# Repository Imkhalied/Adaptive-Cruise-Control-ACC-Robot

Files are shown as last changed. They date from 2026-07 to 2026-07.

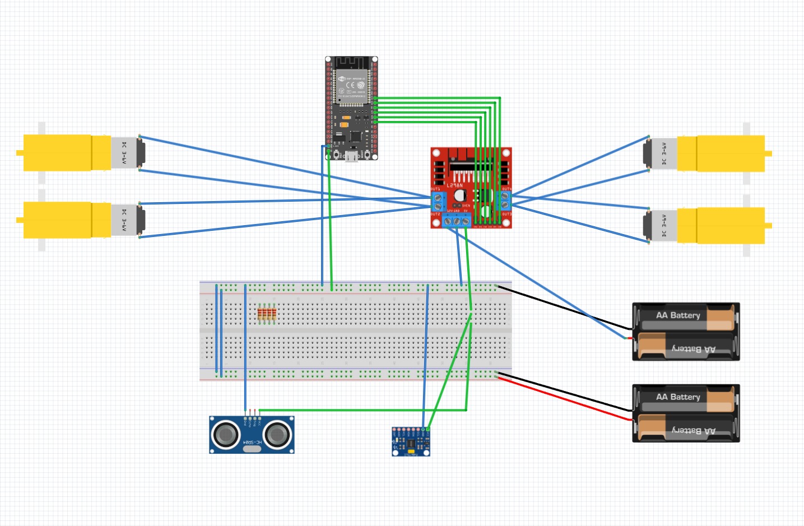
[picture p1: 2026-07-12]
Images/Wiring.jpeg

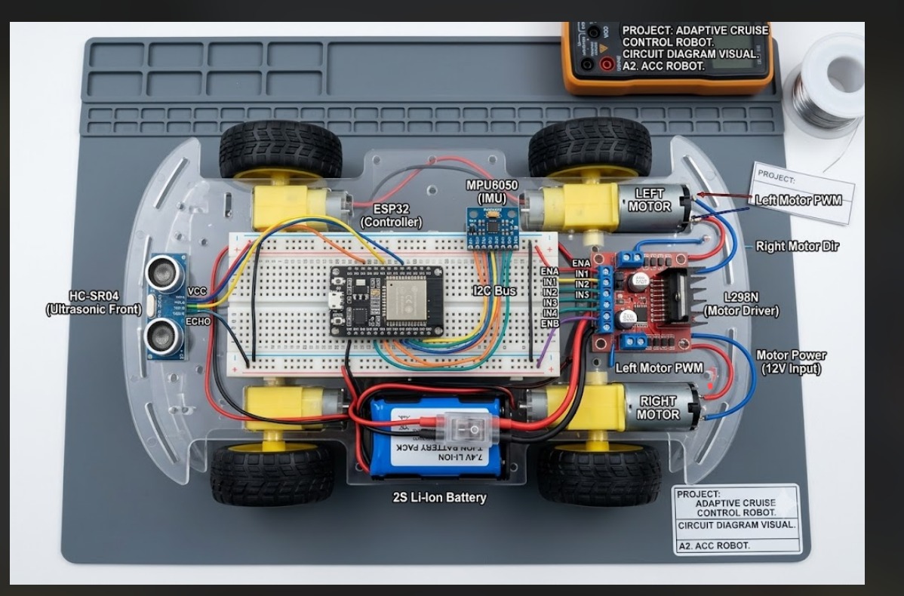
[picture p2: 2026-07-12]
Images/Robot top view.jpeg

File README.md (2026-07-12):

# Adaptive Cruise Control (ACC) Robot using TinyML & PID Control

## Project Overview

Development of an intelligent Adaptive Cruise Control (ACC) robot that combines PID control and TinyML to maintain a safe following distance. The project integrates real-time sensor data, embedded AI, and autonomous speed control on an ESP32 platform.

Completed as the capstone project of the **Robotics & Artificial Intelligence Scholarship Program (90 Hours)** at EncryptCore.

---

## Project Contents

- Adaptive Cruise Control (ACC) robot development
- ESP32 embedded control system
- HC-SR04 ultrasonic distance sensing
- MPU6050 IMU integration
- MATLAB PID controller design and tuning
- Edge Impulse TinyML model training
- Real-world dataset collection and labeling
- AI deployment on ESP32 using the Edge Impulse C++ library
- Hardware design and wiring using Fritzing

---

## Tools Used

- Arduino IDE
- ESP32
- MATLAB
- Edge Impulse
- Fritzing
- C++

---

## Performance

- Robotics & AI Scholarship: **90 Hours**
- TinyML Classification Accuracy: **100%**
- Driving States:
  - Too Close
  - Safe Distance
  - Too Far

---

## Supervision

- Mohamed Mahmoud

---

## Author

Khaled Diaa – Mechatronics Engineering Student

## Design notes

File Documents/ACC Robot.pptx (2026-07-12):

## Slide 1

ADAPTIVE CRUISE CONTROL ROBOT

A Build Guide for a Sensor-Driven, PID-Controlled Follower Robot

ESP32 · HC-SR04 · MPU6050 · L298N · PID Control

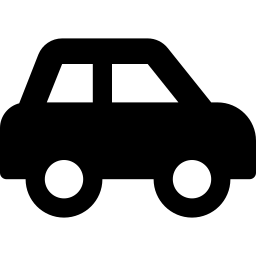
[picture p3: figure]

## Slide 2

Project Overview

What is Adaptive Cruise Control?

Standard cruise control holds a constant speed. ACC intelligently adjusts speed to maintain a safe, pre-defined distance from the vehicle ahead.

System Architecture

Inputs

Distance from HC-SR04, tilt/acceleration from MPU6050

Processing

ESP32 running a PID controller or an AI inference model

Outputs

PWM signals to the L298N driver, commanding the DC motors

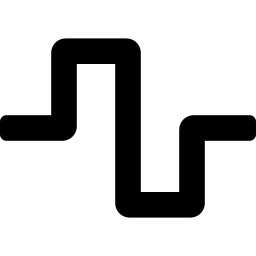
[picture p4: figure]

How Real Vehicles Do It

Radar or LiDAR on the front grille bounces waves off the lead car. Time-of-flight gives distance; if the lead car slows, the ECU commands the brakes and throttle to decelerate.

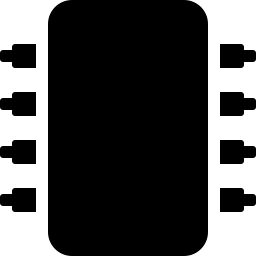
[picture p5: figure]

How Our Robot Mimics It

An HC-SR04 plays radar, the ESP32 plays ECU, and instead of brakes it adjusts PWM to the L298N driver — speeding up or slowing the DC motors via a PID loop or an AI model.

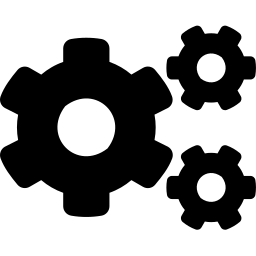
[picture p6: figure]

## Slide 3

Core Components — Sensing & Control

ESP32

3.3V logic · ~500mA peak

The robot's brain. A dual-core 32-bit MCU that runs the control code, reads sensors, and generates PWM. Strictly 3.3V — 5V on a pin can destroy it.

HC-SR04 Ultrasonic

5V · ~15mA

Acts as the radar. Emits a 40kHz pulse from Trig and reads the echo on Echo; distance is derived from time of flight. Struggles with soft or angled surfaces.

MPU6050

3.3–5V · I2C (SDA/SCL)

Accelerometer + gyroscope that detects tilt, bumps, and slopes using MEMS capacitance sensing, feeding the control loop extra context.

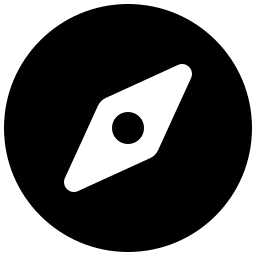
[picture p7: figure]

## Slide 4

Core Components — Drive & Power

L298N Motor Driver

Up to 35V, 2A/channel

A heavy-duty H-Bridge switch that supplies motor current the ESP32 can't provide directly, and lets current reverse for forward/reverse driving. Drops ~2V from battery to motors.

DC Motors + Gearbox

Lorentz force

Convert electrical energy into torque: current through a coil in a magnetic field creates rotational force that turns the wheels.

Battery Pack

2x 18650 Li-Ion, 7.4V

Powers the whole system. Two 18650 cells in series are recommended over a 9V battery, which lacks the capacity this build needs.

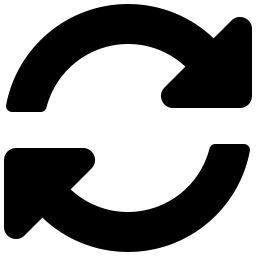
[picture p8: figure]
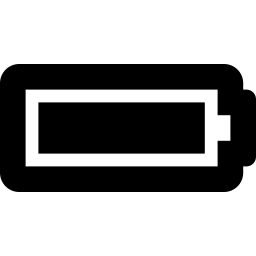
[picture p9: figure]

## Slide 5

Power System

Two 18650 Li-Ion cells in series (3.7V × 2)

7.4V

Nominal voltage

8.4V

Fully charged

2500mAh

Capacity

~3.5 hrs

Estimated runtime

Current Draw

Motors: 2 × ~250mA running (stall up to 1.5A)
ESP32 + sensors: ~200mA
Total average: ~700mA

Protection

Always use a battery holder with a built-in protection circuit (BMS) to prevent discharging the 18650s below 3.0V per cell, which permanently ruins them.

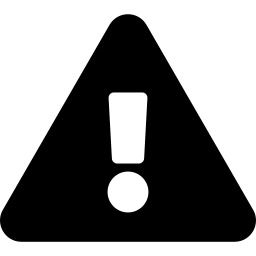
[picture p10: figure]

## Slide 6

Robot Workflow

The robot runs an infinite loop — constantly sensing, thinking, and acting.

1

START

Power on

2

INIT

Set up ESP32 pins, I2C bus; init MPU6050 & HC-SR04

3

SENSE

Trigger HC-SR04, read Echo, calc distance; read MPU6050 tilt

4

FILTER

Apply a moving-average filter to smooth distance spikes

5

DECIDE

Compare filtered distance to target via PID / AI

6

ACT

Send PWM signals to the L298N to drive the motors

→

→

→

→

→

7. REPEAT — loop back to SENSE, continuously

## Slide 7

Distance Control & Filtering

< 10 cm

Emergency Stop

Object too close — speed = 0 immediately

30 cm

Safe Distance

Target distance — robot matches lead speed

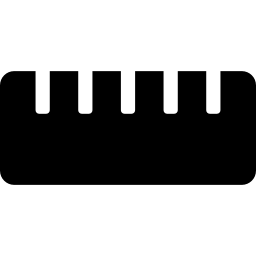
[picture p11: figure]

> 100 cm

Max Following

Object far — robot cruises at top speed

Distance Calculation (Time of Flight)

Distance = (Speed of Sound × Time) / 2

Speed of sound at sea level ≈ 343 m/s (0.0343 cm/µs)

The sound wave travels to the object and back, so the raw time-of-flight is halved.

Moving Average Filter

Filtered = (x₁ + x₂ + ... + xₙ) / n

Ultrasonic readings occasionally spike to "0" or "400cm" from missed echoes.

Keeping the last 5 readings and averaging them smooths out these erratic jumps.

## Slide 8

PID Control

The industry-standard closed-loop control method — calculates an error and outputs a motor speed.

u(t) = Kp·e(t) + Ki∫e(τ)dτ + Kd·de(t)/dt

Proportional (Kp)

Reacts to the present error. Far from 30cm → drive fast; close → drive slow. Can cause overshoot on its own.

Tuning by trial and error:

P

Integral (Ki)

Looks at past error, summing steady-state error over time to nudge the robot if it stalls just short of target.

I

Derivative (Kd)

Predicts future error from the rate of change of distance, acting as a brake to prevent overshoot.

D

- Set Ki and Kd to 0; raise Kp until the robot oscillates around the safe distance.
- Raise Kd to dampen the oscillation so it settles smoothly.
- Raise Ki slightly if the robot stops just short of the target.

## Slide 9

AI / Machine Learning Integration

Instead of classical PID, ML can map sensor inputs directly to motor outputs.

Option 1: Edge Impulse Classification

Data collection: record ultrasonic + MPU accelerometer arrays
Classes: "Too Close", "Safe Distance", "Too Far"
Deployment: exported as an Arduino library; ESP32 runs inference and sets motor speed from the winning class

Recommendation

Option 2: Regression Model

Instead of discrete buckets, regression predicts a continuous PWM speed (0–255) from features like current distance and rate of change of distance.

Gives smoother speed transitions than classification, which tends to produce jerky, stepped changes.

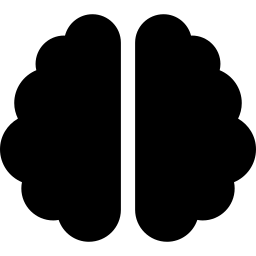
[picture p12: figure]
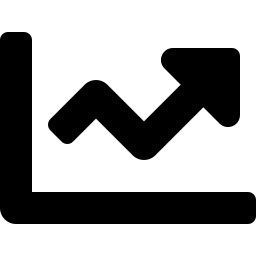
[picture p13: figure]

For a beginner, PID is the standard and most educational approach. If you do use AI, prefer Regression — Classification tends to cause jerky, stepped speed changes.

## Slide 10

Calibration & Testing

Sensor Calibration

HC-SR04:
Measure an object exactly 20cm away with a ruler. Adjust the 0.034 multiplier in code until the Serial Monitor reads exactly 20cm.
MPU6050:
Place the robot on a flat surface. Raw X, Y, Z should read 0, 0, 1g — the deviations are your offsets to subtract in software.

Golden Rule

Never combine sensors and motors on the first power-up. Validate each subsystem in isolation, then integrate one piece at a time.

Order of operations

- Calibrate HC-SR04 distance reading
- Zero the MPU6050 offsets
- Bench-test sensors alone
- Bench-test motors alone (wheels raised)
- Full integration test on the floor

Testing Checklist

- Bench-test sensors: no motors connected — wave a hand in front of the sensor and confirm distance changes on the Serial Monitor

- Bench-test motors: wheels off the ground, force analogWrite(enA, 255) — both should spin forward; swap L298N wiring if one runs backward

- Integration test: on the floor, walk in front of it — does it follow, and stop when you stop?

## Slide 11

Troubleshooting

Problem | Likely Cause | Solution
ESP32 randomly resets/reboots | Voltage drop from motors starting up | Power ESP32 from a separate buck converter, or add a large capacitor across the power rails
Robot stutters / shakes | PID Kp is too high (overshoot) | Decrease Kp; increase Kd slightly
Motors hum but don't spin | PWM speed is below the motor's deadband | Add a minimum baseline speed in code (e.g. if speed > 0, speed += 50)
Distance reads 0cm randomly | Ultrasonic echo timed out | Implement a software filter to ignore 0 readings

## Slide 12

Future Improvements

Once the base robot works, consider these engineering upgrades:

Wheel Encoders

The control loop is currently "open-loop" for the motors — we guess that a PWM of 150 equals a certain speed. Wheel encoders measure actual wheel RPM, enabling a cascaded PID loop: the distance PID outputs a target RPM, and a speed PID achieves it.

Sensor Fusion

Combine HC-SR04 distance with MPU6050 accelerometer data using a Kalman Filter to predict where the lead vehicle is, even when the ultrasonic sensor temporarily misses a ping.

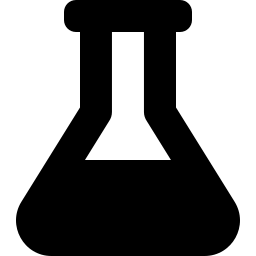
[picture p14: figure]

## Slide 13

Final Deliverables

Through this guide, you now have:

A complete architectural overview of an ACC system

A detailed pin mapping and wiring strategy for voltage compatibility

A structural workflow and flowchart logic

The mathematical foundation of PID control

A starter codebase demonstrating proportional control

Testing, calibration, and troubleshooting protocols

Take your time with the wiring, build the circuit incrementally, and test each component alone before combining them into the final control loop. Good luck with your build!

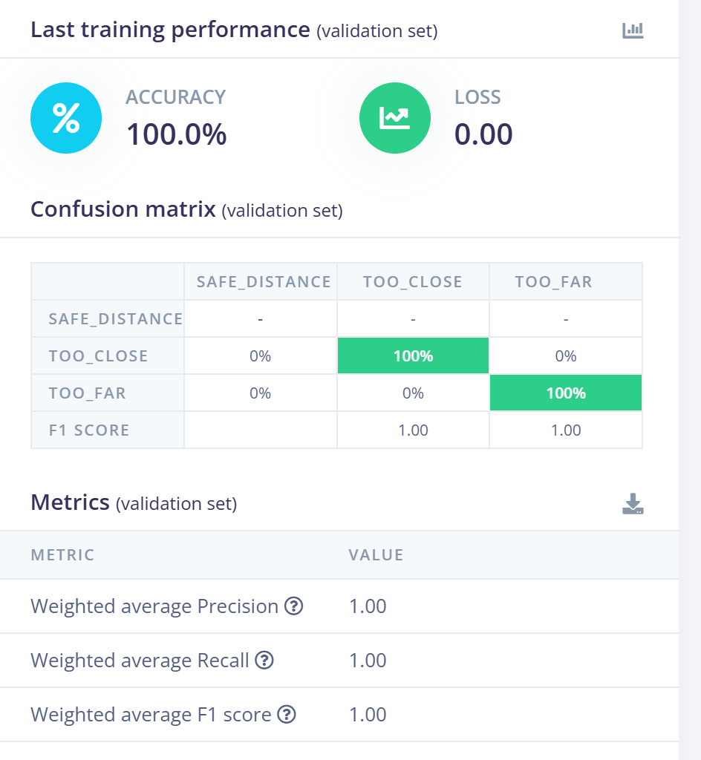
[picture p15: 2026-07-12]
Images/Model Accuracy.png

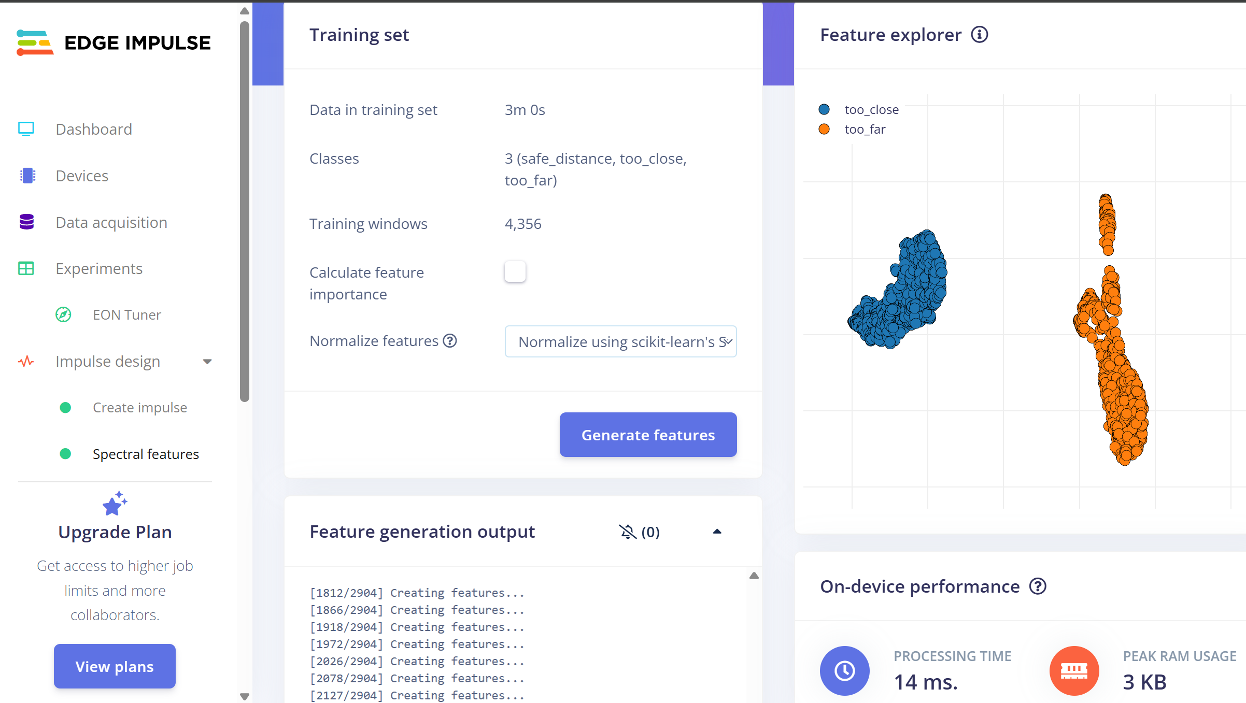
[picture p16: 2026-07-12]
Images/Model Traning.png

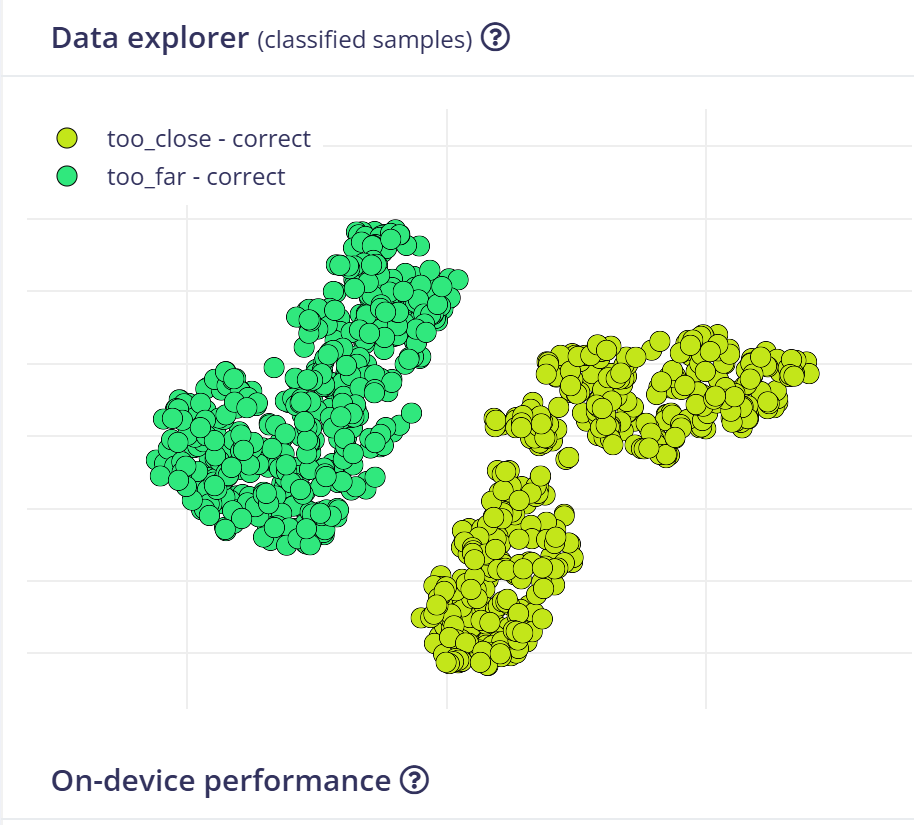
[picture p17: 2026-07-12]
Images/model Classified.png

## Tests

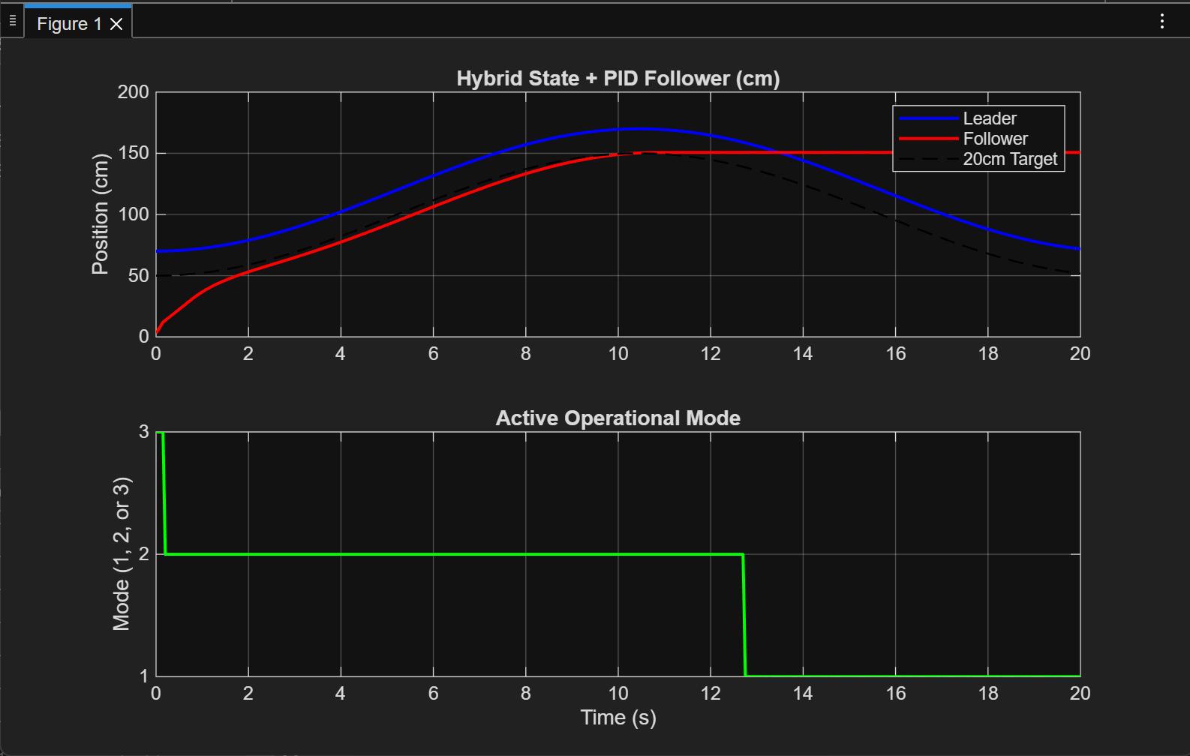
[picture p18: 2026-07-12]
Images/Matlab results.png

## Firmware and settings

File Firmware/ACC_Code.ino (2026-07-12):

// =====================================================
// ROBOT 2 — FOLLOWER (PID + HC-SR04 + Edge Impulse AI)
// Maintains fixed distance behind Leader.
// Emergency brake if gap < 8cm.
// PID setpoint tracks Leader's actual gap in real time.
// Edge Impulse fusion classifier ("safe_distance" /
// "too_close" / "too_far") runs alongside the PID loop
// and can override/bias motor output as a safety layer.
//
// FIXED FOR ESP32 ARDUINO CORE 3.x:
// ledcSetup() / ledcAttachPin() were removed in core 3.x.
// New API attaches LEDC directly to a pin with ledcAttach(),
// and writes duty cycle with ledcWrite(pin, duty) — no more
// separate channel numbers to manage.
//
// ── EDGE IMPULSE SETUP (read this first) ────────────
// 1. Install the library: Arduino IDE > Sketch > Include
//    Library > Add .ZIP Library... > select the ORIGINAL
//    zip (ei-ai-project-arduino-1_0_2-impulse-_1.zip),
//    not the extracted folder. That registers it correctly
//    under the name "AI_project_inferencing".
// 2. This is a SENSOR FUSION model: 8 axes/frame, 50
//    frames/window, sampled at 50 Hz (20 ms/sample) -> a
//    1-second window per inference. Its DSP block uses an
//    FFT + low-pass filter (9.7 Hz cutoff), so the 50 Hz
//    sample rate must be hit consistently or accuracy will
//    degrade — this is why the loop below is restructured
//    to be non-blocking (millis()-based) instead of using
//    delay().
// 3. IMPORTANT — VERIFY THE FEATURE ORDER: the exported
//    library does NOT embed axis names for fusion projects,
//    so the exact order of the 8 values below is an
//    assumption, not a certainty. I picked the most likely
//    layout given your hardware (HC-SR04 + MPU6050) and the
//    labels (safe_distance/too_close/too_far):
//
//      [0] distance_filtered (cm)
//      [1] distance_raw      (cm)
//      [2] accX (m/s^2)
//      [3] accY (m/s^2)
//      [4] accZ (m/s^2)
//      [5] gyroX (deg/s)
//      [6] gyroY (deg/s)
//      [7] gyroZ (deg/s)
//
//    Open your Edge Impulse project > Data acquisition, and
//    check the sensor/axis order shown for your recorded
//    samples. If it differs, reorder ONLY the 8 lines inside
//    sampleFeatures() below — nothing else needs to change.
// =====================================================

#include <Wire.h>
#include <MPU6050.h>
#include <AI_project_inferencing.h>   // Edge Impulse: AI_project

// ── HC-SR04 ──────────────────────────────────────────
#define TRIG  5
#define ECHO 18

// ── Motor Pins ──────────────────────────────────────
#define ENA  25
#define IN1  26
#define IN2  27
#define ENB  14
#define IN3  12
#define IN4  13

#define PWM_FREQ 1000
#define PWM_RES  8

// ── PID Parameters (TUNE THESE) ─────────────────────
float Kp = 3.0;
float Ki = 0.05;
float Kd = 1.5;

const float TARGET_DIST   = 20.0;  // cm — desired following gap
const float ESTOP_DIST    =  8.0;  // cm — emergency brake threshold
const float TOO_FAR_DIST  = 60.0;  // cm — max range before full speed
const float MAX_PWM       = 220.0;
const float MIN_PWM       =  60.0;

// ── PID state ───────────────────────────────────────
float prevError  = 0;
float integral   = 0;
unsigned long prevTime = 0;

// ── MPU6050 ─────────────────────────────────────────
MPU6050 mpu;
int16_t rawAx, rawAy, rawAz, rawGx, rawGy, rawGz;

// ── Sensor noise filter ─────────────────────────────
float distFiltered = TARGET_DIST;
const float ALPHA = 0.3;   // Low-pass: 0=frozen, 1=raw

// ── Control loop timing (non-blocking) ──────────────
const unsigned long CONTROL_INTERVAL_MS = 40;  // ~25 Hz, same as before
unsigned long lastControlMs = 0;

// =====================================================
// EDGE IMPULSE — feature buffer & classifier plumbing
// =====================================================
#define EI_SAMPLE_INTERVAL_MS (1000 / EI_CLASSIFIER_FREQUENCY)  // 20 ms @ 50 Hz
static float eiFeatures[EI_CLASSIFIER_RAW_SAMPLE_COUNT * EI_CLASSIFIER_RAW_SAMPLES_PER_FRAME]; // 50*8 = 400
static size_t eiFeatureIx = 0;
unsigned long lastEiSampleMs = 0;

// Latest classifier verdict, used by the control loop
enum FollowState { STATE_SAFE, STATE_TOO_CLOSE, STATE_TOO_FAR, STATE_UNKNOWN };
FollowState eiState = STATE_UNKNOWN;
float eiConfidence = 0.0f;

// Required by the Edge Impulse SDK: feeds raw features to the classifier
int raw_feature_get_data(size_t offset, size_t length, float *out_ptr) {
  memcpy(out_ptr, eiFeatures + offset, length * sizeof(float));
  return 0;
}

// Grabs one frame (8 values) of sensor data for the EI feature buffer.
// See the "VERIFY THE FEATURE ORDER" note at the top of this file.
void sampleFeatures() {
  float rawDist = readDistance();
  distFiltered = ALPHA * rawDist + (1.0f - ALPHA) * distFiltered;

  mpu.getMotion6(&rawAx, &rawAy, &rawAz, &rawGx, &rawGy, &rawGz);
  float accX = (rawAx / 16384.0f) * 9.80665f;
  float accY = (rawAy / 16384.0f) * 9.80665f;
  float accZ = (rawAz / 16384.0f) * 9.80665f;
  float gyroX = rawGx / 131.0f;
  float gyroY = rawGy / 131.0f;
  float gyroZ = rawGz / 131.0f;

  if (eiFeatureIx + 8 <= EI_CLASSIFIER_RAW_SAMPLE_COUNT * EI_CLASSIFIER_RAW_SAMPLES_PER_FRAME) {
    eiFeatures[eiFeatureIx++] = distFiltered;
    eiFeatures[eiFeatureIx++] = rawDist;
    eiFeatures[eiFeatureIx++] = accX;
    eiFeatures[eiFeatureIx++] = accY;
    eiFeatures[eiFeatureIx++] = accZ;
    eiFeatures[eiFeatureIx++] = gyroX;
    eiFeatures[eiFeatureIx++] = gyroY;
    eiFeatures[eiFeatureIx++] = gyroZ;
  }
}

// Runs once the 1-second window (400 floats) is full.
void runClassifier() {
  signal_t signal;
  signal.total_length = EI_CLASSIFIER_RAW_SAMPLE_COUNT * EI_CLASSIFIER_RAW_SAMPLES_PER_FRAME;
  signal.get_data = &raw_feature_get_data;

  ei_impulse_result_t result = { 0 };
  EI_IMPULSE_ERROR err = run_classifier(&signal, &result, false);
  if (err != EI_IMPULSE_OK) {
    Serial.print("EI classifier error: "); Serial.println((int)err);
    return;
  }

  // Pick the highest-confidence label
  float bestValue = 0.0f;
  const char *bestLabel = "unknown";
  for (size_t ix = 0; ix < EI_CLASSIFIER_LABEL_COUNT; ix++) {
    if (result.classification[ix].value > bestValue) {
      bestValue = result.classification[ix].value;
      bestLabel = result.classification[ix].label;
    }
  }
  eiConfidence = bestValue;

  if (strcmp(bestLabel, "too_close") == 0) eiState = STATE_TOO_CLOSE;
  else if (strcmp(bestLabel, "too_far") == 0) eiState = STATE_TOO_FAR;
  else if (strcmp(bestLabel, "safe_distance") == 0) eiState = STATE_SAFE;
  else eiState = STATE_UNKNOWN;

  Serial.print("EI -> "); Serial.print(bestLabel);
  Serial.print(" ("); Serial.print(bestValue * 100.0f, 1); Serial.println("%)");
}

void setup() {
  Serial.begin(115200);

  pinMode(TRIG, OUTPUT);
  pinMode(ECHO, INPUT);
  pinMode(IN1, OUTPUT); pinMode(IN2, OUTPUT);
  pinMode(IN3, OUTPUT); pinMode(IN4, OUTPUT);

  // New core 3.x LEDC API: attach frequency+resolution directly to the pin.
  // Returns the actual frequency achieved (or 0 on failure) — worth checking.
  ledcAttach(ENA, PWM_FREQ, PWM_RES);
  ledcAttach(ENB, PWM_FREQ, PWM_RES);

  Wire.begin();
  mpu.initialize();
  if (!mpu.testConnection()) Serial.println("MPU6050 FAIL");

  prevTime = millis();
  lastControlMs = millis();
  lastEiSampleMs = millis();
  Serial.println("Follower ready (with Edge Impulse classifier).");
}

// ── Read Distance ───────────────────────────────────
float readDistance() {
  digitalWrite(TRIG, LOW);  delayMicroseconds(2);
  digitalWrite(TRIG, HIGH); delayMicroseconds(10);
  digitalWrite(TRIG, LOW);
  long dur = pulseIn(ECHO, HIGH, 25000);  // 25ms timeout
  if (dur == 0) return TOO_FAR_DIST;      // no echo = too far
  return (dur * 0.0343f) / 2.0f;
}

// ── Motor Control ───────────────────────────────────
void driveForward(int pwm) {
  pwm = constrain(pwm, 0, 255);
  digitalWrite(IN1, HIGH); digitalWrite(IN2, LOW);
  digitalWrite(IN3, HIGH); digitalWrite(IN4, LOW);
  ledcWrite(ENA, pwm);
  ledcWrite(ENB, pwm);
}

void driveReverse(int pwm) {
  pwm = constrain(pwm, 0, 255);
  digitalWrite(IN1, LOW);  digitalWrite(IN2, HIGH);
  digitalWrite(IN3, LOW);  digitalWrite(IN4, HIGH);
  ledcWrite(ENA, pwm);
  ledcWrite(ENB, pwm);
}

void stopMotors() {
  digitalWrite(IN1, LOW); digitalWrite(IN2, LOW);
  digitalWrite(IN3, LOW); digitalWrite(IN4, LOW);
  ledcWrite(ENA, 0);
  ledcWrite(ENB, 0);
}

// ── Slope feedforward (MPU6050) ──────────────────────
float slopeFeedforward() {
  int16_t ax, ay, az;
  mpu.getAcceleration(&ax, &ay, &az);
  float az_g = az / 16384.0f;
  // Climbing (az_g>1.05) → boost speed; descending → reduce
  return constrain((az_g - 1.0f) * 40.0f, -50.0f, 50.0f);
}

// ── PID Compute ─────────────────────────────────────
float computePID(float dist) {
  unsigned long now = millis();
  float dt = (now - prevTime) / 1000.0f;
  if (dt < 0.001f) dt = 0.001f;
  prevTime = now;

  float error = dist - TARGET_DIST;  // positive = too far → speed up

  // Anti-windup: clamp integral
  if (abs(error) < 40.0f) {
    integral += error * dt;
    integral = constrain(integral, -80.0f, 80.0f);
  } else {
    integral *= 0.9f;  // decay when far off target
  }

  float derivative = (error - prevError) / dt;
  prevError = error;

  return (Kp * error) + (Ki * integral) + (Kd * derivative);
}

void loop() {
  unsigned long now = millis();

  // ── EI sampling task: 50 Hz, matches the model's training rate ──
  if (now - lastEiSampleMs >= EI_SAMPLE_INTERVAL_MS) {
    lastEiSampleMs = now;
    sampleFeatures();
    if (eiFeatureIx >= EI_CLASSIFIER_RAW_SAMPLE_COUNT * EI_CLASSIFIER_RAW_SAMPLES_PER_FRAME) {
      runClassifier();
      eiFeatureIx = 0;  // start filling the next 1-second window
    }
  }

  // ── Control task: ~25 Hz, drives the motors ──
  if (now - lastControlMs < CONTROL_INTERVAL_MS) return;
  lastControlMs = now;

  // distFiltered is kept up to date by sampleFeatures() above (50 Hz),
  // so the control loop just reads the latest value.

  // 1. Hardware emergency stop (always wins, independent of the model)
  if (distFiltered < ESTOP_DIST) {
    stopMotors();
    integral = 0;
    Serial.println("!!! EMERGENCY STOP (HC-SR04) !!!");
    return;
  }

  // 2. AI safety layer: if the classifier is confident the gap is
  //    dangerously close, brake even if the raw threshold hasn't
  //    tripped yet (e.g. it's picking up motion cues the single
  //    ultrasonic reading misses).
  if (eiState == STATE_TOO_CLOSE && eiConfidence > 0.7f) {
    stopMotors();
    integral = 0;
    Serial.println("!!! EI SAFETY STOP (too_close) !!!");
    return;
  }

  // 3. PID (with a small bias from the classifier's "too_far" verdict)
  float pid    = computePID(distFiltered);
  float slope  = slopeFeedforward();
  float eiBias = (eiState == STATE_TOO_FAR && eiConfidence > 0.7f) ? 15.0f : 0.0f;
  float output = pid + slope + eiBias;

  // 4. Drive
  if (output > 0) {
    float pwm = constrain(abs(output), MIN_PWM, MAX_PWM);
    driveForward((int)pwm);
  } else if (output < -20) {
    driveReverse((int)constrain(abs(output), 40, 120));
  } else {
    stopMotors();
  }

  // 5. Serial Plotter (open at 115200)
  Serial.print("Dist:"); Serial.print(distFiltered);
  Serial.print(",Target:"); Serial.print(TARGET_DIST);
  Serial.print(",PID:"); Serial.print(output);
  Serial.print(",EStop:"); Serial.print(ESTOP_DIST);
  Serial.print(",EIState:"); Serial.println((int)eiState);
}
